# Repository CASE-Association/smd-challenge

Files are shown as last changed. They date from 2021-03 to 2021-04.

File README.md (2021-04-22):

(Currently work in progress)

# CASE SMD Challenge

Inspired by [this unfortunate SMD project](https://hackaday.io/project/25265-an-unfortunate-smd-project) we have created the CASE SMD Challenge to provide our members with an opportunity for immense soldering frustration. If you are able to fully assemble the board it also doubles as  a small USB development board. You can now flash all the LED:s that were painstakingly added to the board or hook it up to other gizmos via the test points on the PCB.

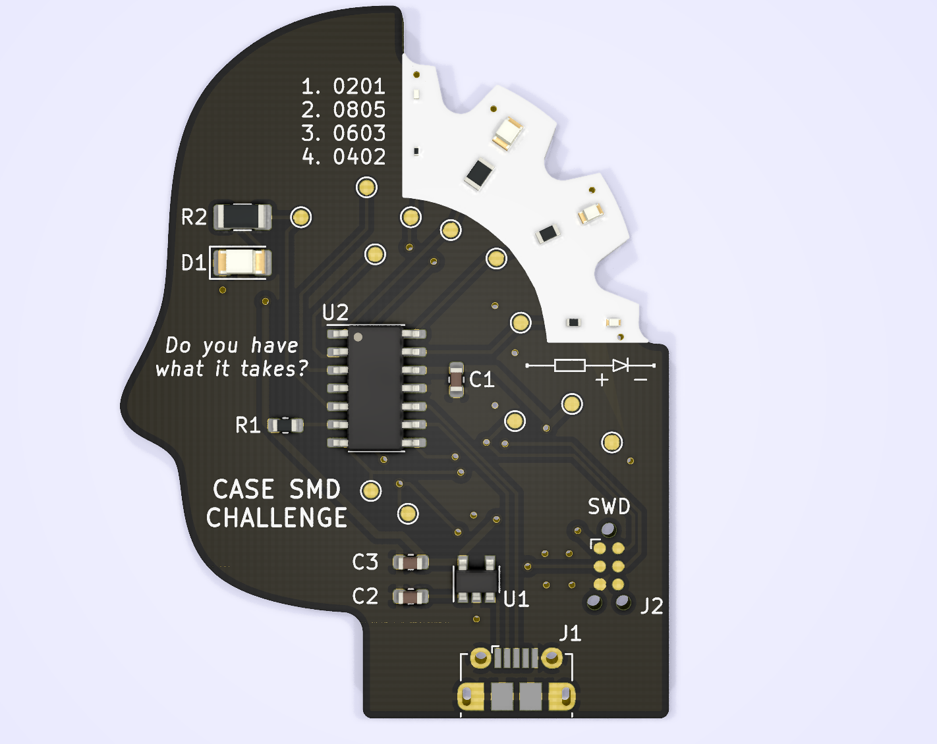
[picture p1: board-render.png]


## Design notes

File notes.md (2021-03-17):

## Reasons for samd11

- Relatively cheap (under 10 sek @ 25 qty)
- Native USB programming through Arduino IDE
- SOIC makes soldering easy

## Good sources on using samd 11

1. [Breadboarding with usb connection](https://funwithsoftware.org/posts/2019-09-01-breadboard-samd11-part1.html)
2. [Orginal Twitter insp](https://twitter.com/timonsku/status/1213479459375980544)
3. [Hackaday io project with example board](https://hackaday.io/project/10210-dixi-arduino-sam-d11-usb-stick)
   Schematics seem to be in eagle .sch file?
4. [Forked samd core for arduino](https://github.com/mattairtech/ArduinoCore-samd)
   Makes bootloader install easy, available as a boards install if you add specific url in arduino IDE.

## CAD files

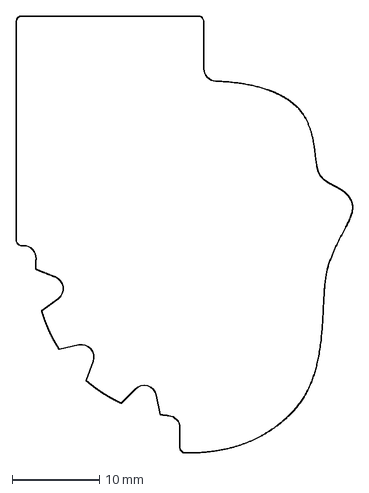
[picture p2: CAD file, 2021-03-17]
hw/outline.dxf
38.5 x 50.0 mm

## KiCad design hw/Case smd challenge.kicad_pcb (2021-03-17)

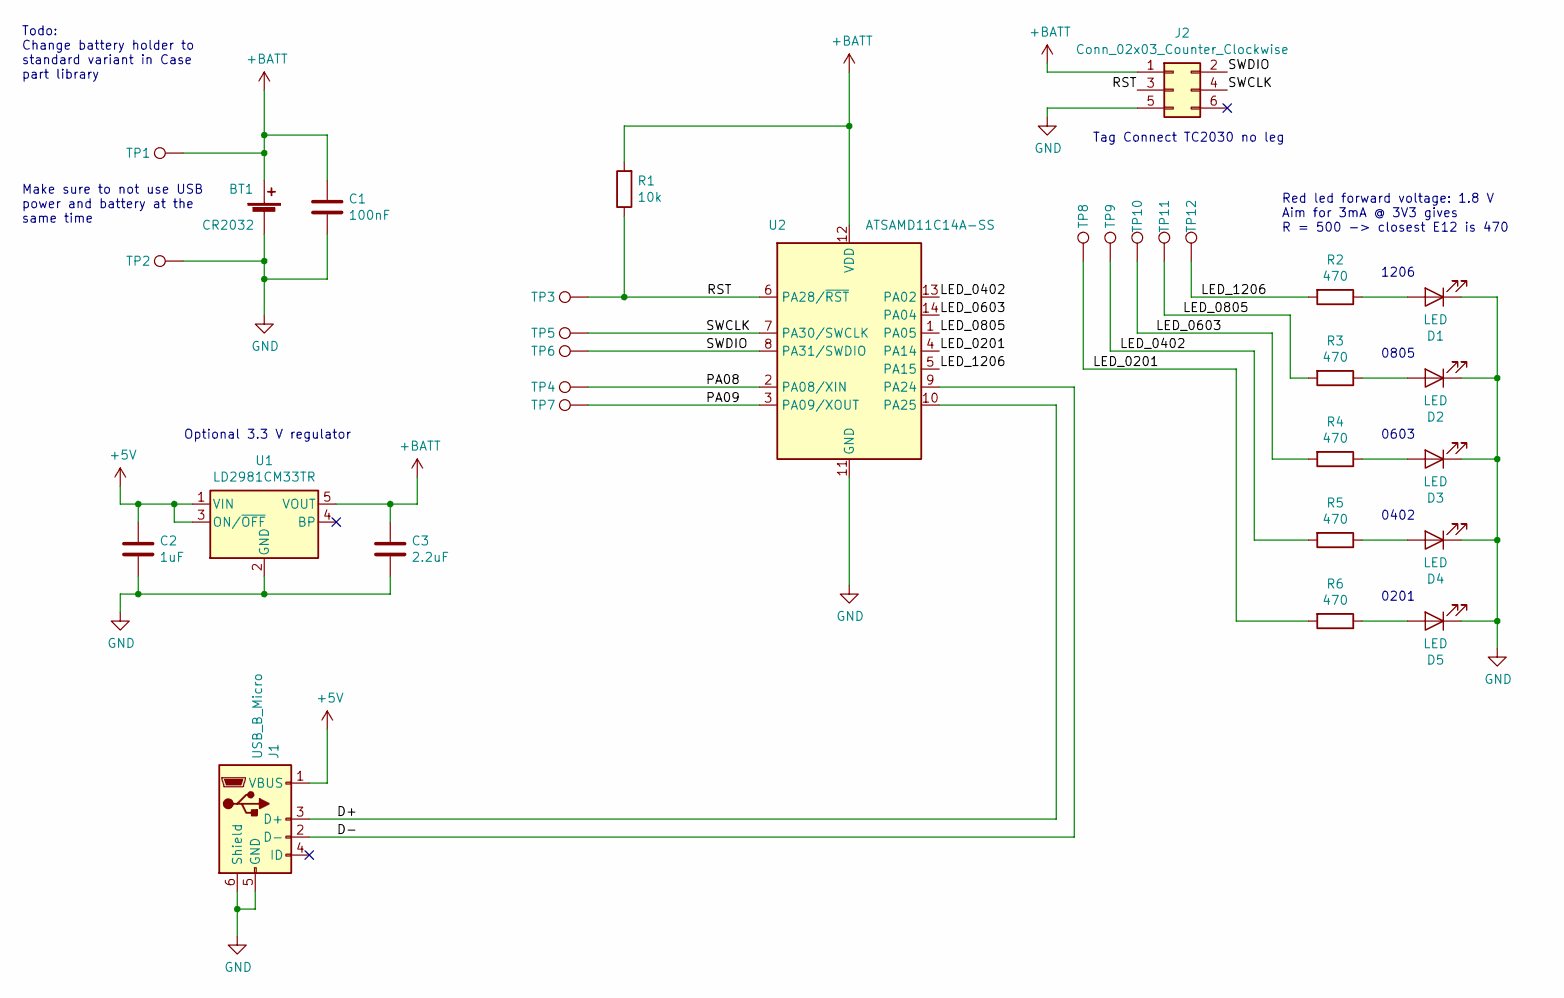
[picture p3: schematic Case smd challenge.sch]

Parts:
BT1: CR2032; BatteryHolder_Keystone_3002_1x2032; MPN 3002TR
C1: 100nF; C_0603_1608Metric
C2: 1uF; C_0603_1608Metric
C3: 2.2uF; C_0603_1608Metric
D1: LED; LED_1206_3216Metric; MPN 150120RS75000
D2: LED; LED_0805_2012Metric; MPN LH R974-LP-1
D3: LED; LED_0603_1608Metric; MPN SML-D12U1WT86
D4: LED; LED_0402_1005Metric; MPN SML-P12VTT86R
D5: LED; LED_0201_0603Metric; MPN APG0603SEC-E-TT
J1: USB_B_Micro; USB_Micro-B_Molex-105017-0001
J2: Conn_02x03_Counter_Clockwise; Tag-Connect_TC2030-IDC-NL_2x03_P1.27mm_Vertical
R1: 10k; R_0603_1608Metric
R2: 470; R_1206_3216Metric; MPN RMCF1206JT470R
R3: 470; R_0805_2012Metric; MPN RMCF0805JT470R
R4: 470; R_0603_1608Metric; MPN RMCF0603JT470R
R5: 470; R_0402_1005Metric; MPN RMCF0402JT470R
R6: 470; R_0201_0603Metric; MPN RMCF0201JT470R
TP1, TP2, TP3, TP4, TP5, TP6, TP7, TP8, TP9, TP10, TP11, TP12: TestPoint; TestPoint_Pad_D1.0mm
U1: LD2981CM33TR; SOT-23-5
U2: ATSAMD11C14A-SS; SOIC-14_3.9x8.7mm_P1.27mm; MPN ATSAMD11C14A-SSUT

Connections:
+5V: C2.1, J1.1 (VBUS), U1.1 (VIN), U1.3 (ON/~OFF~)
+BATT: BT1.1 (+), C1.1, C3.1, J2.1, R1.2, TP1.1, U1.5 (VOUT), U2.12 (VDD)
/D+: J1.3 (D+), U2.10 (PA25)
/D-: J1.2 (D-), U2.9 (PA24)
/LED_0201: R6.2, TP8.1, U2.4 (PA14)
/LED_0402: R5.2, TP9.1, U2.13 (PA02)
/LED_0603: R4.2, TP10.1, U2.14 (PA04)
/LED_0805: R3.2, TP11.1, U2.1 (PA05)
/LED_1206: R2.2, TP12.1, U2.5 (PA15)
/PA08: TP4.1, U2.2 (PA08/XIN)
/PA09: TP7.1, U2.3 (PA09/XOUT)
/RST: J2.3, R1.1, TP3.1, U2.6 (PA28/~RST)
/SWCLK: J2.4, TP5.1, U2.7 (PA30/SWCLK)
/SWDIO: J2.2, TP6.1, U2.8 (PA31/SWDIO)
GND: BT1.2 (-), C1.2, C2.2, C3.2, D1.1 (K), D2.1 (K), D3.1 (K), D4.1 (K), D5.1 (K), J1.5 (GND), J1.6 (Shield), J2.5, TP2.1, U1.2 (GND), U2.11 (GND)
unnamed: D1.2 (A), R2.1
unnamed: D2.2 (A), R3.1
unnamed: D3.2 (A), R4.1
unnamed: D4.2 (A), R5.1
unnamed: D5.2 (A), R6.1

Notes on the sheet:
0805
0603
0402
0201
1206
Optional 3.3 V regulator
Make sure to not use USB power and battery at the same time
Tag Connect TC2030 no leg
Red led forward voltage: 1.8 V Aim for 3mA @ 3V3 gives R = 500 -> closest E12 is 470
Todo: Change battery holder to standard variant in Case part library

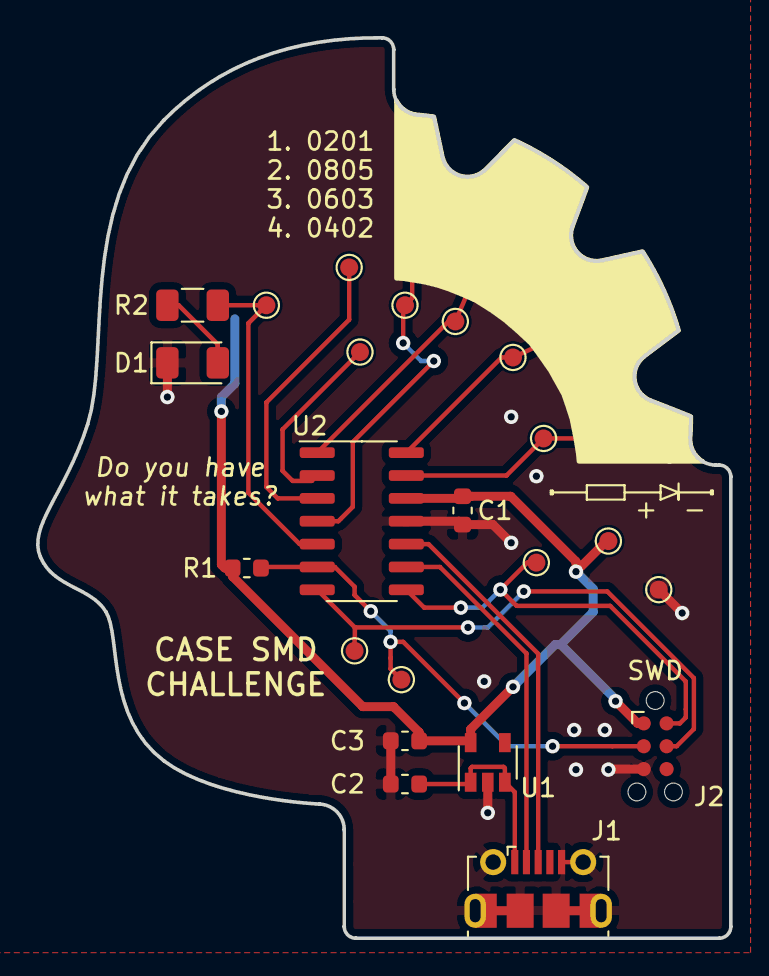
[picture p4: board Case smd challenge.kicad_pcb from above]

Board: 2 copper layers, 38.5 x 50.0 mm, 31 parts (1 on the bottom side), 20 nets.

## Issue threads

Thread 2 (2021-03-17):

Figure out Bootloader and USB code upload

noel-danielsson, 2021-03-17:
Goal is to flash a bootloader so that the board can be easily programmed from Arduino IDE or similar.
Check out links in [notes](https://github.com/CASE-Association/smd-challenge/blob/main/notes.md)
